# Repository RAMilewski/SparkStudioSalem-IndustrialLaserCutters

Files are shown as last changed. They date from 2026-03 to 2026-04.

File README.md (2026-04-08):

# Industrial 6090 150Watt CO2 Laser Cutters

This repository collects information about the Industrial
scale CO2 laser cutters at Spark Studios including
policies, safety information, training materials and technical
information such as wiring diagrams.

# Policies and procedures

This section covers the policies and procedures for operating the machines.

* Use of these machines is governed by the [Policies](policies.pdf).
* When running jobs, please follow the [Operations Checklist](operation-checklist.pdf)
* When running jobs, please fill out a sheet in the [Operation Log](operation-log.pdf)
* Different materials should be cut and engraved with various settings.  While you may
  need to experiment to get the best results, the [Feeds and Speeds](FeedsAndSpeeds.pdf) document
  gives good starting points for common materials.
* To achieve better surface finishes, please refer to the [Pro Tips](pro-tips.pdf)
* These [Signs](signs.pdf) should be placed on the machines in event of malfunction to alert
  other users and Spark Studio board members of malfunctions.

If you wish th revise the policies, please edit the corresponding
OpenOffice (.odt) files and review with the Spark Studio Board.
Once approved, a pull-request can be sent to request that the official
copies of the policies be updated.  Note when revising policies, the
revision number and date MUST be updated in order to keep track
of which policy revision is the most recent.

# Technical Information

This section contains technical information for maintenance and
diagnosis of problems.  These are indended only for those tasked
specifically with maintaining and repairing the machines.  These
should not be used during normal operation.

This [operation manual](Gweike-operation-manual.pdf) covers
the use and operation of a similar laser cutter from Gweike.
While the laser cutters are not exactly this model, they
do give useful guidance on the machines and their operation.

The 6090 laser cutters are built using a Ruida controller
which interprets the GCode to guide the machine through making
cuts.  The [Ruida controller's documentation](RDC6445G-Control-System-V1.2-Manual.pdf)
describes more about its design and usage.

In addition, the [laser power supply has accompanying documentation](LASERPOWERSUPPLY欧规_1729590679720.pdf)
about its inputs and controls.

This [wiring diagram](laser-block-diagram.pdf) is
available for helping to understand the design of the
machines and general troubleshooting.  This diagram was produced
by reverse-engineering the design and is not authoritative,
but is as accurate as possible a diagram describing the wiring
of the machine based on its current configuration which has
been slightly altered from its original design.  The diagram is
authored in KiCad and future changes should be proposed and updated
using this format, reviewed, and implemented with the consent of
a Certifier or the Spark Studio Board.

# Modified Parts

Some parts have been designed and 3d printed in an effort to
improve the safety of the equipment.  These include:

* Spacers/stand-offs to hold a panel to prevent laser light from coming
  through the vent holes.
  
* Plugs for circular holes in front of Blue laser cutter.

* Holder for reed switch protecting the laser from firing with
  the door open.

The CAD for these files are maintained in this [FreeCAD file](LaserCutterParts.FCStd).

# Alignment Procedures

The performance of the machines is highly dependent on how well
the machine is aligned.  Specifically, the optics must be aligned
closely with the gantry and the gantry needs to be square and parallel to
the bed.  Alignment of the machine is something of an art, but the
procedures are roughly outlined in the [Laser Alignment Guide](LaserAlignmentGuide.pdf).
These alignment procedures make use of some 3d-printed targets and
a [Laser Beam Alignment Worksheet](LaserBeamAlignmentWorksheet.svg) to assist in visualizing the beam path
and adjustments needed to bring the beam into the correct orientation.

There are beam target fixtures that can be inserted into the
apertures of [Mirror #2](stl/LaserCutterParts-P_AlignmentTarget_Mirror2.stl)
and [Mirror #3](stl/LaserCutterParts-P_AlignmentTarget_Mirror3.stl)
and affixed with blue painter's tape and marked using the [aperture](stl/LaserCutterParts-P_AlignmentTarget_ScribeAperture.stl) and [aperture](stl/LaserCutterParts-P_AlignmentTarget_Scribe.stl) marking jigs so that objective measurements can be made of beam position at each point in the beam path.

Source models for each of these parts can be found in
the [FreeCAD file](LaserCutterParts.FCStd) in case modifications to the models
are required.

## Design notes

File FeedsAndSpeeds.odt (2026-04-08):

Feeds and Speeds

Feed rate (cutting speed) and Power (percentage of maximum laser power) typically need to be tuned for each material. Even among the same material, there is often variation, so the numbers presented here are just starting points. Some adjustment of these settings are usually necessary to achieve the results you’re looking for. Because of this, it is advised to cut some test samples before cutting a large project to ensure that you’re getting good results. Note that in order to extend the life of the laser, it is advised to never exceed 50% power.

## Material: Plywood

| Cut | | Engrave/Score
Thickness | Power (%) | Speed (mm/s) | Power(%) | Speed(mm/s)
3mm (1/8 in) | 50 | 30 | 15 | 200
5mm (3/16 in) | 50 | 10-13 | 15 | 200

## Material: Acrylic

| Cut | | Engrave/Score
Thickness | Power (%) | Speed (mm/s) | Power(%) | Speed(mm/s)
3mm (1/8 in) | 50 | 30 | 15 | 200
5mm (3/16 in) | 50 | 7-10 | 15 | 200

## Material: High density fiber board (Hardboard or HDF)

| Cut | | Engrave/Score
Thickness | Power (%) | Speed (mm/s) | Power(%) | Speed(mm/s)
3mm (1/8 in) | 50 | 30 | 15 | 200
5mm (3/16 in) | 50 | 10-13 | 15 | 200

## Material: Ceramic Tile

| Cut | | Engrave/Score
Thickness | Power (%) | Speed (mm/s) | Power(%) | Speed(mm/s)
Any | N/A | N/A | 15 | 200-300

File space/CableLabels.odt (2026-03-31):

Network Cables

5G Router

Internet Ingress

See Network Diagram

5G Router to SW1

SW1

Ethernet Switch

See Network Diagram

SW1 to 5G Router

SW1 to SW2

Access Point 1

See Network Diagram

Access Point 1 to SW1 (PoE Port)

Access Point 2

See Network Diagram

Access Point 2 to SW2 (PoE Port)

SW2

Ethernet Switch

See Network Diagram

SW2 to SW3

SW2 to Access Point (PoE Port)

SW3

Ethernet Switch

See Network Diagram

SW3 to SW2

SW3 to Gweike Laser

SW3 to Blue Laser

Breaker Labels

Breaker: B1 : Northwest Warehouse Plugs

Breaker: B3 : Bathroom

Breaker: B3 : Bathroom

Breaker: B3 : Bathroom

Breaker: B5 : Warehouse Heater

Breaker: B7 : Loft lights and network

Breaker: B9 : Unterminated (danger)

Breaker: B11,B13 : 220VAC Under breaker panel

Breaker: B15,B17 : Mini-split AC unit

Breaker: B19 : Conference room

Breaker: B19 : Conference room

Breaker: B19 : Conference room

Breaker: B19 : Conference room

Breaker: B21 : East Wall “Pop” (Blue&White Laser cutter)

Breaker: B23 : East Wall “Crackle” (Gweike)

Breaker: B25 : Northeast Wall 3d printers, “Snap” GlowForge

Breaker: B27 : East Wall Electronics Bench

Breaker: B2 : Warehouse Lights

Breaker: B4, B6 : Water Heater

Breaker: B8 : Overhead Power Drop

Breaker: B10 : Outside Lights

Breaker: B12,B14 : Do not turn off/ Unknown(?)

Breaker: B16,B18 : Bathroom Heater

Breaker: B20,B22,B24 : Laser Exhaust Fans

Breaker: B26,B28,B30 : Air Compressor Panel

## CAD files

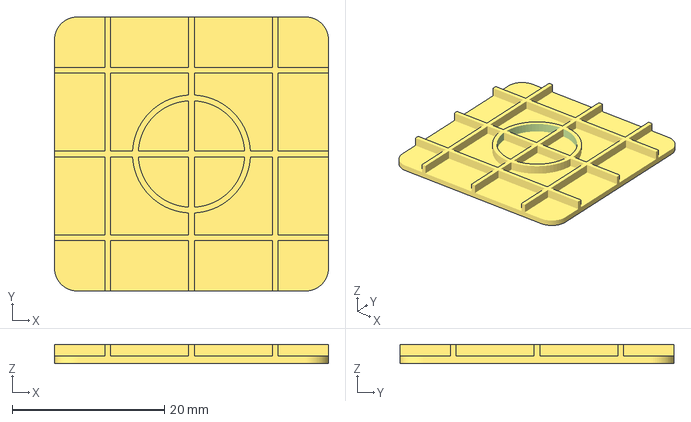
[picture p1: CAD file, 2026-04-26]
3mf/StampSurface.3mf
36.0 x 36.0 x 2.50 mm

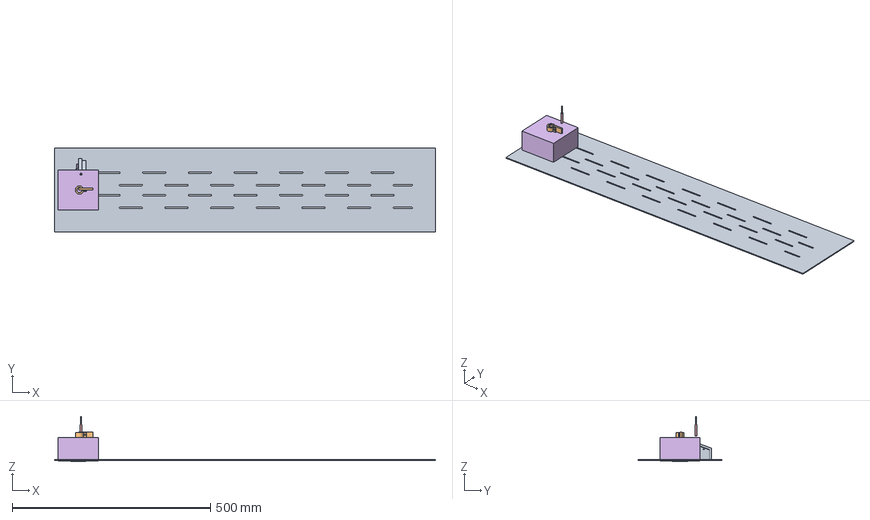
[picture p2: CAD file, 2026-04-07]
LaserCutterParts.FCStd
961.4 x 211.8 x 114.3 mm
B_FrontPanel
B_FrontPanelBaffle_Spacer
B_FrontPanelBaffle_Endcap
B_LimitSwitchSpacer
B_HolePlug_FrontPanels
B_HolePlug_Tester
B_ReedSwitch_Magnet
B_ReedSwitch_Holder
B_Cabinet_Body
B_Cabinet_Lid
B_ReedSwitch
B_CAMTest
B_TPLinkBracket_Right
B_TPLinkBracket_Left
B_AlignmentWrench1
B_AlignmentWrench2
B_AlignmentTarget_Mirror3
B_AlignmentTarget_Mirror2
B_HolePlug_SidePanels
B_AlignmentTarget_Stamp
B_AlignmentTarget_Scribe
B_IndicatorMount
B_AlignmentTarget_ScribeAperture
B_AlignmentTarget_HeadTube
B_AlignmentTarget_HeadTarget
B_LaserPointerMount
B_LaserPointerMountAperture
Model-P_CAMTest
CutTool
Stock
5mm Endmill

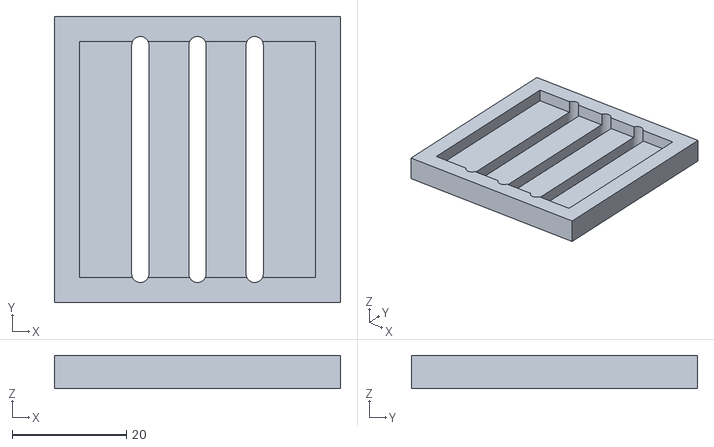
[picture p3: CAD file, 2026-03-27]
stl/LaserCutterParts-P_AlignmentTarget_Scribe.stl
50.0 x 50.0 x 5.80

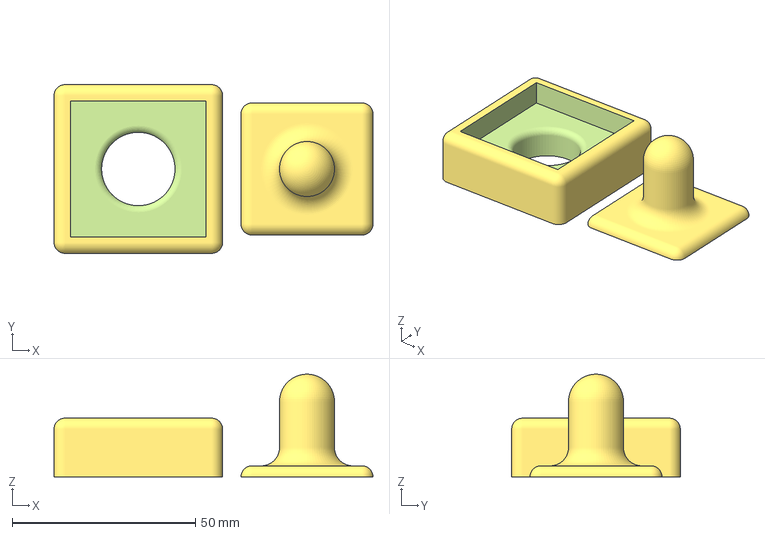
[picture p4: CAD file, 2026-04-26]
3mf/AlignmentStamp.3mf
87.0 x 46.0 x 28.0 mm

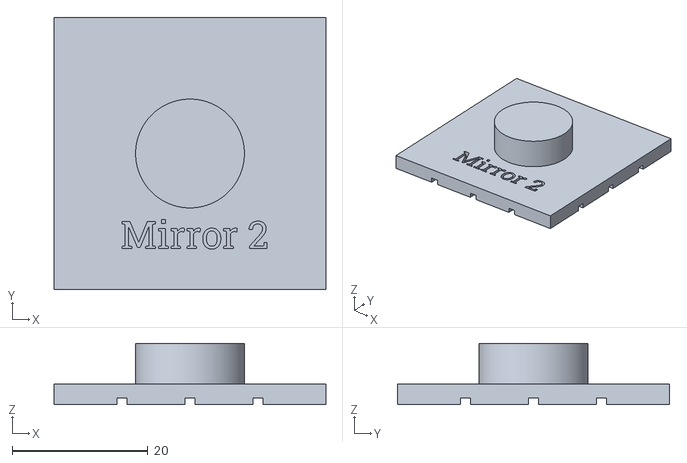
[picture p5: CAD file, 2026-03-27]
stl/LaserCutterParts-P_AlignmentTarget_Mirror2.stl
40.0 x 40.0 x 9.00

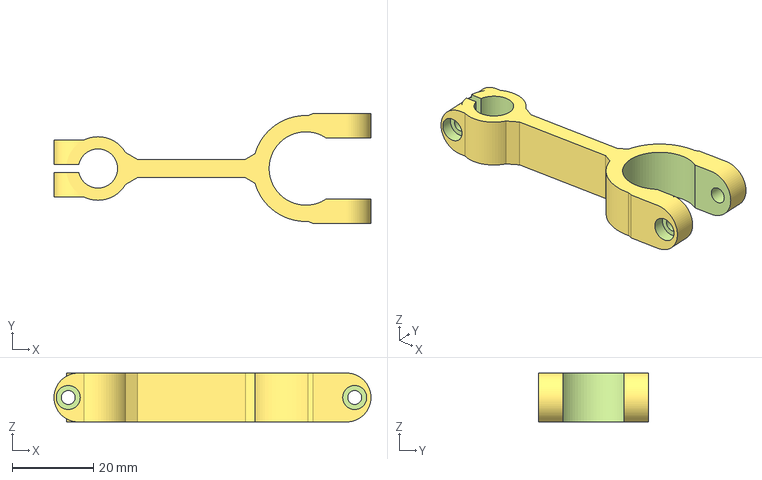
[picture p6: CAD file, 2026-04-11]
3mf/dial_holder.3mf
77.8 x 27.0 x 12.0 mm

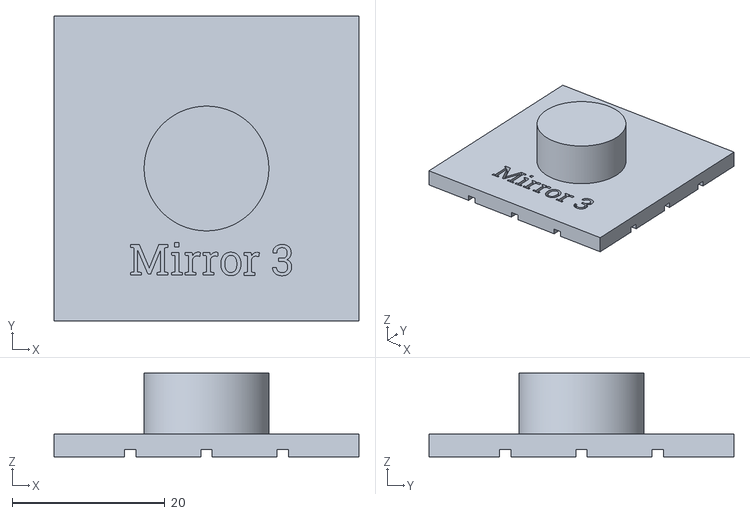
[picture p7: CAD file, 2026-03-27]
stl/LaserCutterParts-P_AlignmentTarget_Mirror3.stl
40.0 x 40.0 x 11.0

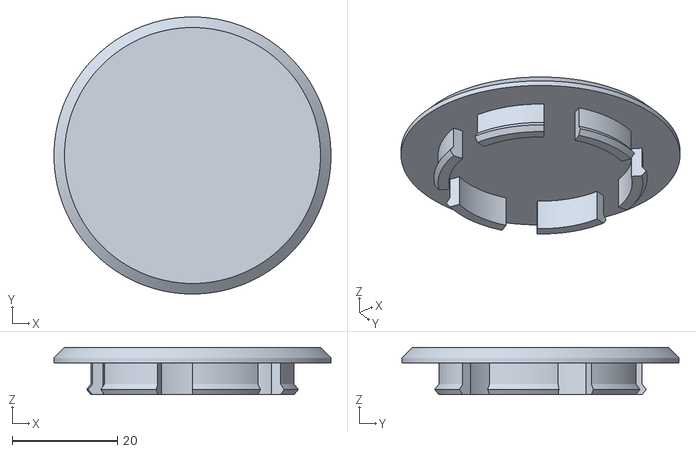
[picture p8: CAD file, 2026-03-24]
stl/LaserCutterParts-P_HolePlug_FrontPanels.stl
52.6 x 52.6 x 9.00

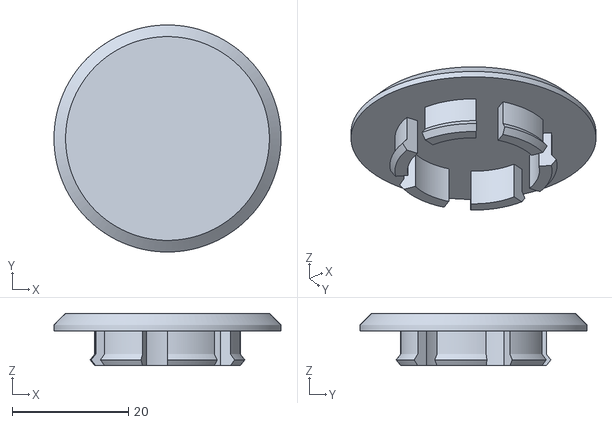
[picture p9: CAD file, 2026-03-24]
stl/LaserCutterParts-P_HolePlug_SidePanels.stl
39.0 x 39.0 x 9.00

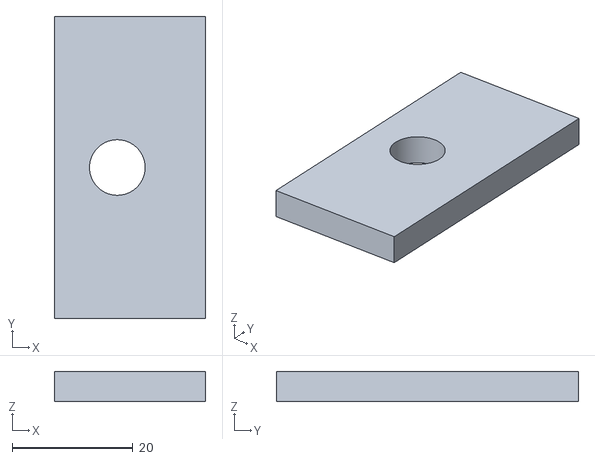
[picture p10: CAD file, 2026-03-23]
stl/LaserCutterParts-P_LimitSwitch_Magnet.stl
25.0 x 50.0 x 5.00

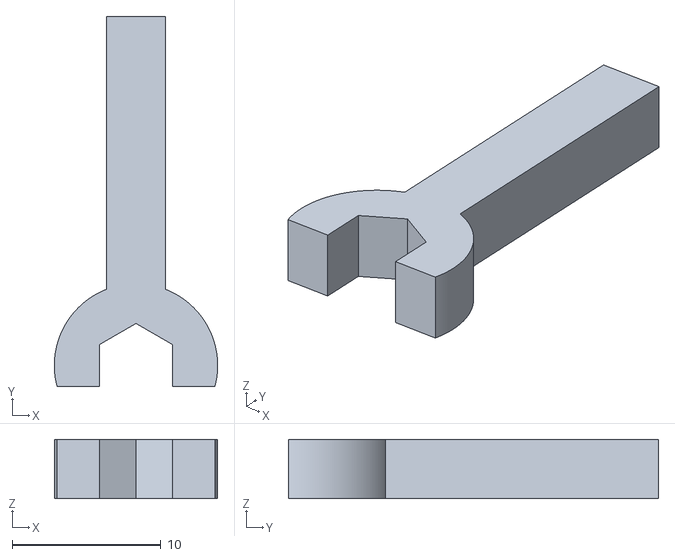
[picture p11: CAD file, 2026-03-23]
stl/LaserCutterParts-P_AlignmentWrench1_4_9mm.stl
11.0 x 24.9 x 4.00

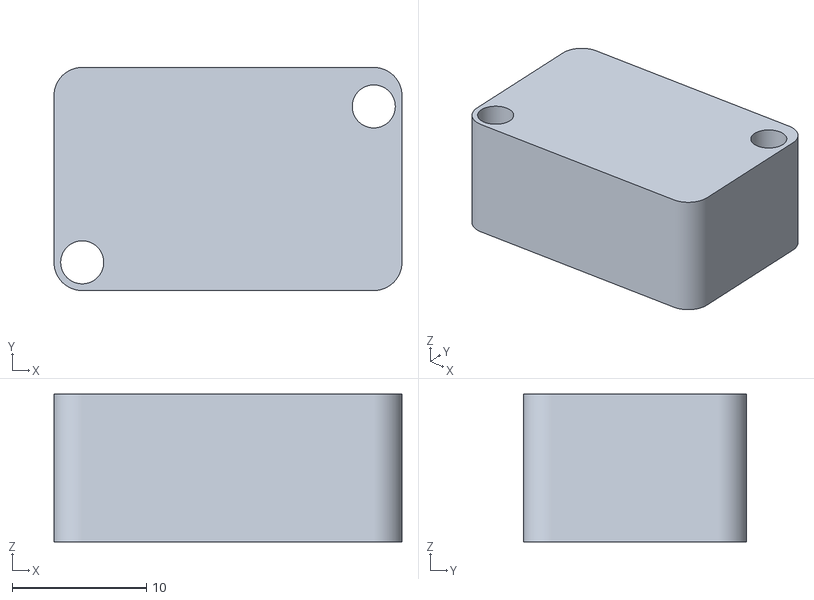
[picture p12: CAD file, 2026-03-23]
stl/LaserCutterParts-P_LimitSwitchSpacer.stl
25.9 x 16.6 x 11.0

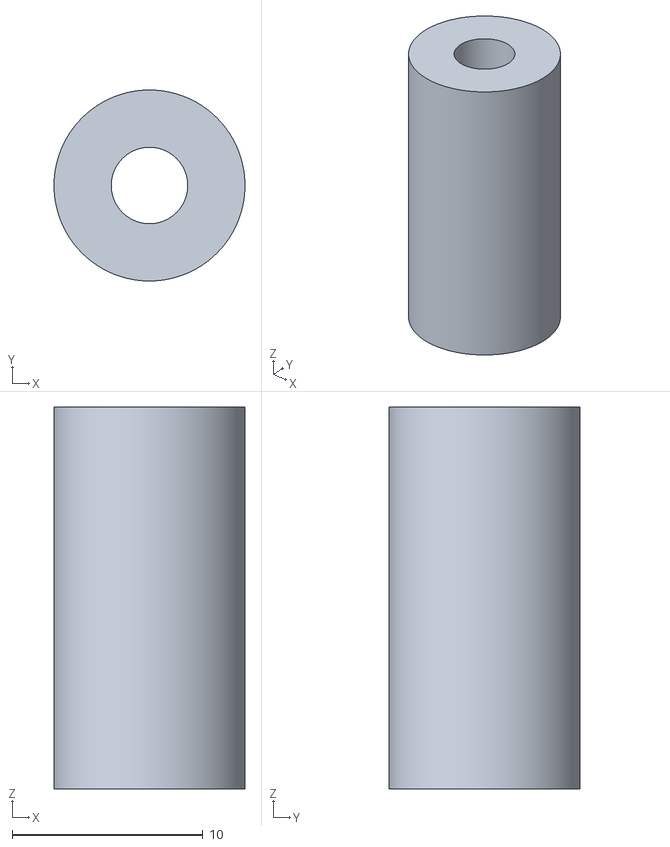
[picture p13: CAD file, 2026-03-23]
stl/LaserCutterParts-P_Spacer.stl
10.00 x 10.00 x 20.0

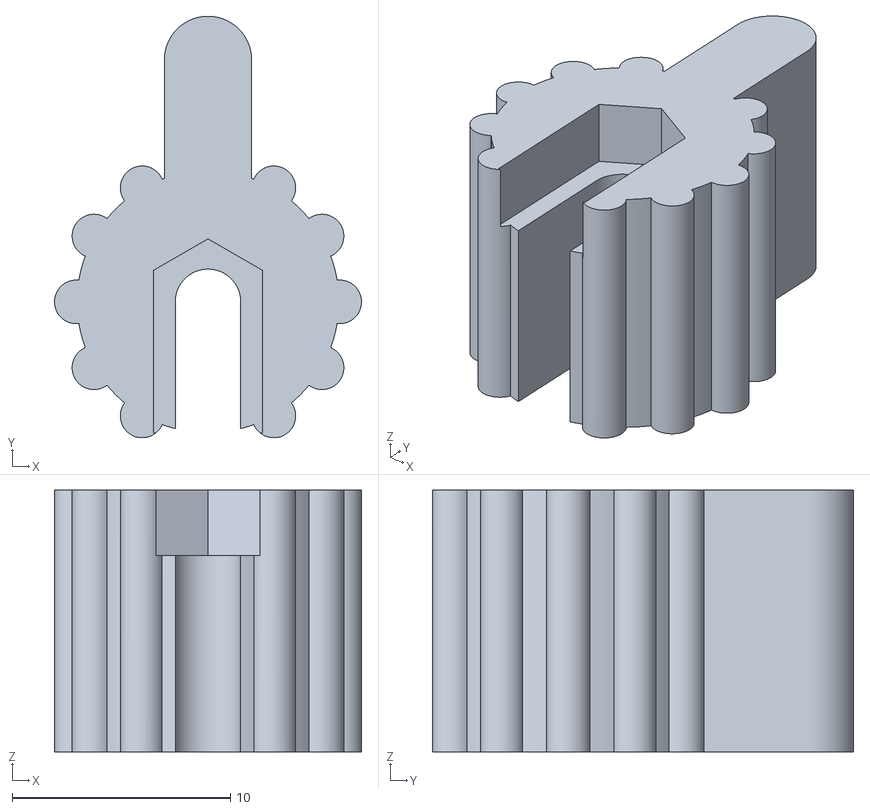
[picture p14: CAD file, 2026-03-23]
stl/LaserCutterParts-P_AlignmentWrench2.stl
14.1 x 19.3 x 12.0

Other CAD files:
stl/LaserCutterParts-P_AlignmentTarget_ScribeAperture.stl
stl/LaserCutterParts-P_ReedSwitch_Magnet.stl
stl/LaserCutterParts-P_AlignmentWrench2_5mm.stl
stl/LaserCutterParts-P_AlignmentWrench1_5mm.stl
OpenSCAD/AlignmentStamp.scad
OpenSCAD/dial_holder.scad
stl/LaserCutterParts-P_AlignmentWrench.stl
stl/LaserCutterParts-P_AlignmentWrench1_5_1mm.stl
stl/LaserCutterParts-P_AlignmentWrench2_4_9mm.stl
stl/LaserCutterParts-P_AlignmentWrench2_5_1mm.stl
stl/LaserCutterParts-P_Endcap.stl
stl/LaserCutterParts-P_HolePlug_FrontPanelsTester.stl
stl/LaserCutterParts-P_LimitSwitch_Switch.stl
stl/LaserCutterParts-P_PowerBox_Body.stl
stl/LaserCutterParts-P_PowerBox_Lid.stl
stl/LaserCutterParts-P_ReedSwitch_Holder.stl
stl/LaserCutterParts-P_TPLinkBracket.stl
stl/LaserCutterParts-P_TPLinkBracket_Left.stl
stl/LaserCutterParts-P_TPLinkBracket_Right.stl

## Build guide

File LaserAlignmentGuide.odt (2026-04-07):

Outline of procedures to align the gantry, optics, and bed

# Introduction

The performance of these laser cutters is highly dependent on how well the machine is aligned and calibrated. The alignment of the machine is something of an art and requires patience and understanding of the fundamentals of optics. Fortunately, if inspected regularly, the full procedure is rarely needed. This document contains an outline of the main alignment procedures and also a monthly maintenance guide. Once aligned, the machine should be maintained by following the monthly inspection process to verify that the machine is still adequately aligned and perform minor adjustments as needed. This is intended to ensure that the full alignment process is needed only rarely and that most of the time, only minor adjustments are needed to keep the machine in working order.

# Alignment Procedure Outline

## 1. Gantry Skew

In this stage, we aim to align the gantry so that the left and right rails are parallel. Using a bubble-level, check that each of the rails is angled from front-to-back by the same amount. If necessary, the entire machine can be trammed so that they are both level as closely as possible. Note that precise alignment is not necessary, but try to get the left and right rails within about 1 degree of the same angle front-to-back. The height of the front anchor point of each of the rails can be adjusted by loosening the screws holding the Y axis rails to the chassis and moving them higher or lower. Continue iterating on this until they are as close to parallel as you can make them. [Ref 1].

This is not too crucial for the optics because mirror #2 rides along the rails. Any “skew” in the yz plane will be washed out because the mirror moves with the rail. Nonetheless, make an effort to ensure that the rails are as level as possible in reference to one another.

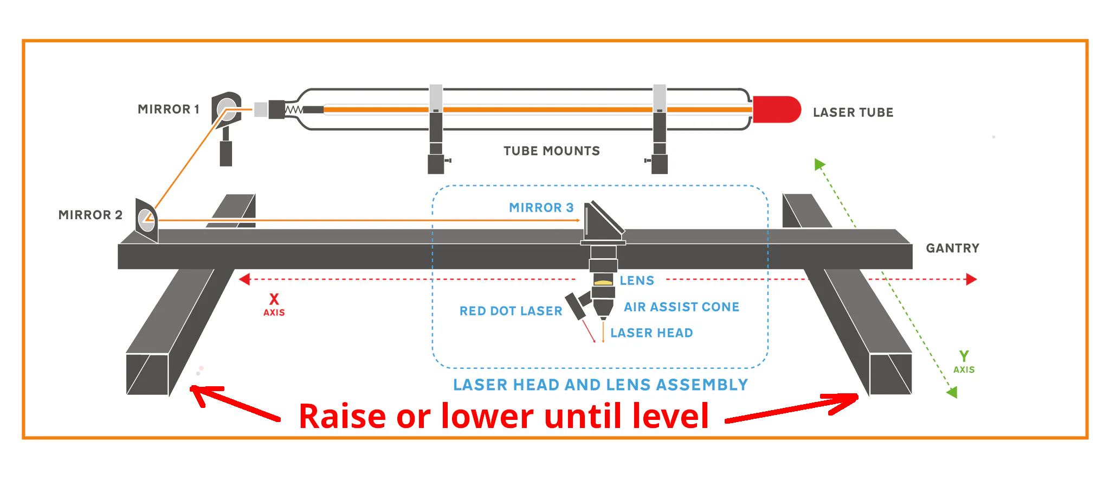
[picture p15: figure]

Measuring gantry skew. In order to check the gantry for skew, use a piece of fine thread stretched taught on the two diagonals of the gantry rails. If the gantry is square in the YZ plane, the two threads will intersect at the center. If one is higher or lower, then the rails are not perfectly parallel. Raise or lower the gantry until the two threads are just barely touching. You can secure the thread at each end with magnets or tape so they remain tight while making adjustments. Make sure to remove the thread after adjustment.

## 2. Gantry Mirror Interference

It sometimes happens that mirror #2 mounted on the gantry is accidentally bumped by the drag chain, cables, or other impediments. It only takes a microscopic deflection to move the mirror and thus beam spot at the far end of the machine. Take care to ensure that the cables, drag chain, and other moving parts do not bump or interfere with the free motion of the mirror mounted on the gantry.

## 3. Bed Leveling

In this stage, we aim to ensure that the XY plane of the bed is parallel to the XY plane of the gantry. The easiest way to do this is to place a large rigid, square object on the bed. Ideally, this object should be a) flat b) rigid, and c) cover the entire bed.

Next, jog the laser head to each of the 4 corners and use a small flat object to move the laser head so that the lowest of the 4 corners just touches the object. Our aim from here will be to adjust the z-axis lead screws so that all 4 corners match. To adjust one of the lead screws, use a hex wrench to loosen the set screw for the sprocket for that lead screw and manually adjust the lead screw until it just touches the object or the dial indicator reads the correct height. Re-tighten the set screw for the sprocket to lock the position in place. Continue this process until all 4 corners read the same height in reference to the tip of the laser tube.

For extra precision, a dial indicator can be mounted on the laser lens tube. Once done, the laser head can carefully be moved around the bed to measure how much deviation there is across the bed. A good alignment should yield something on the order of 10 thousandths of an inch (0.254mm)

This image depicts using a dial-indicator mounted on the laser lens aperture to measure relative height of the bed against the plane of the gantry. Note that the indicator SHOULD NOT BE MOUNTED UNTIL THE CONTROLLER HAS BEEN TURNED ON AND HOMED. You don’t want the indicator to be dragged by the controller over the bed during homing as this can damage the indicator and possibly crash the head.

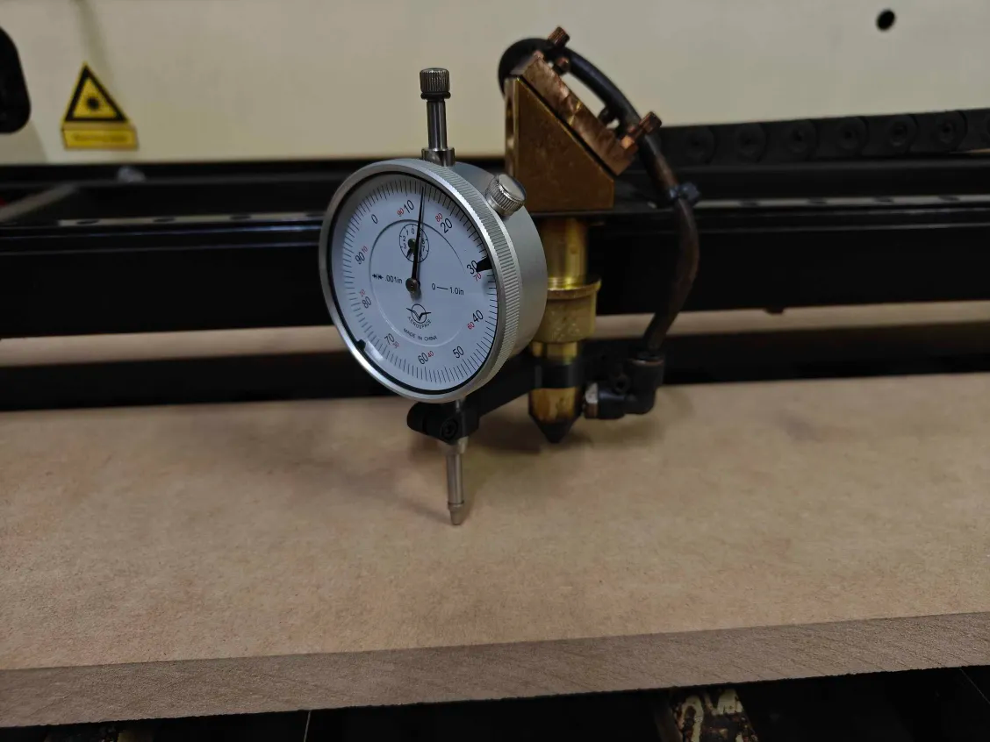
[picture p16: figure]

Once the indicator can measure the height in different locations, the bed can be adjusted carefully to raise or lower the corners until the bed and gantry are in the same plane.

[Ref 2]

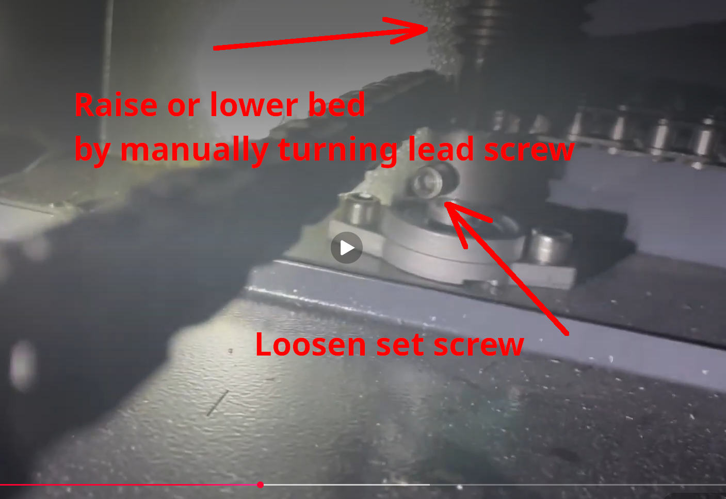
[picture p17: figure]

## 4. Tube Adjustment

In this stage, we aim to ensure that the laser beam arrives at mirror #1 in the center of the aperture. In order to do this, it may be necessary to shim the laser tube or make fine adjustments to the tube location until the beam arrives at the center as parallel as possible. Note that it is difficult to ensure that the tube is exactly perpendicular to the aperture because there is only a very small gap between the end of the laser tube and the aperture, but align it as closely as possible with the naked eye. Alignments of the mirrors will make up for small deviations from the correct angle.

## 5. Mirror 1 Adjustment

In this stage, we aim to ensure that the laser beam arrives at mirror #2 at the center of the aperture.

Place a piece of blue painter’s tape over one of the “Mirror 2 Target”, mark the grid and aperture location with a pen using the accompanying templates. These markings will assist in objectively knowing the position of the test pulse in reference to the aperture and a 10x10mm grid.

Then, place the target in the input aperture of mirror #2. Close the lid and power on the laser. Fire a test pulse at 10% power with the laser head in the upper-left corner of the bed (closest to the laser head). Repeat this process in the lower-left corner. If the pulses arrive in different locations, carefully adjust the set-screws on mirorr #1 for the up/down and left/right to move the beam in the desired direction. Note that when adjusting the mirror, the one in the “lower” corner will move a larger distance than the one in the “upper” corner. Repeat this adjustment until both pulses arrive in the approximate center of the aperture and as close to one another as possible.

Note that after aligning mirror #2, it may be necessary to further adjust mirror #1, but this should be the approximate starting location for further alignment.

## 6. Mirror 2 Alignment

In this stage, we aim to ensure that the laser beam arrives at mirror #3 (the mirror on the laser head) in the exact center of the aperture consistently all the way across the bed.

Place a piece of blue painter’s tape across one a “Mirror 3 Target” and mark the grid and aperture location with a pen using the accompanying templates. These markings will assist in objectively knowing the position of the test pulse in reference to the aperture and a 10x10mm grid.

Then place the target in the input aperture of mirror #3. Jog the laser head to the upper-left corner of the bed. Fire a test pulse at 10% power. Repeat this for each of the 4 corners. It is sometimes helpful to save these pulses by sticking them to a copy of the “Laser Alignment Worksheet”. This will give the location of the pulses on each of the 4 corners of the bed.

Adjusting the set-screws on mirror #2 will move each of those pulses up and down or left and right. Note that there will be more movement of the beam on the right side than the left, but the motion of them should be approximately the same. For example, if the upper-right and lower-right test spots are both 4mm high, you would want to adjust mirror #2 downward. Doing this would move both the upper-right and lower-right spots downward by the same amount. It is usually not the case that they will move in different directions or by different amounts.

Also note that the right side spots will move more than the left-side spots. This is because the left-side spots are a very small distance from mirror #2 than the right-side spots.

Begin the adjustment by carefully adjusting the “left/right” screw until all 4 spots are as close to the center as possible and cluster around it. For example, if they’re not quite aligned, you goal would be to put one spot slightly to the left and the other slightly to the right. Once the left/right is approximately on center, proceed to the “up/down” adjustment.

Again, for the “up/down” adjustment of mirror #2, you should aim to get all 4 spots as close to the center as possible. If they’re not quite aligned, you should aim to get them evenly distributed above/below so that “on average” they’re in the same location.

If the 4 test spots are within about 1-2mm of center, that is usually sufficient. If so, skip to step 8. If not, it may be required to re-adjust mirror #1 (Step 6) and then come back to mirror #2 (Step 5).

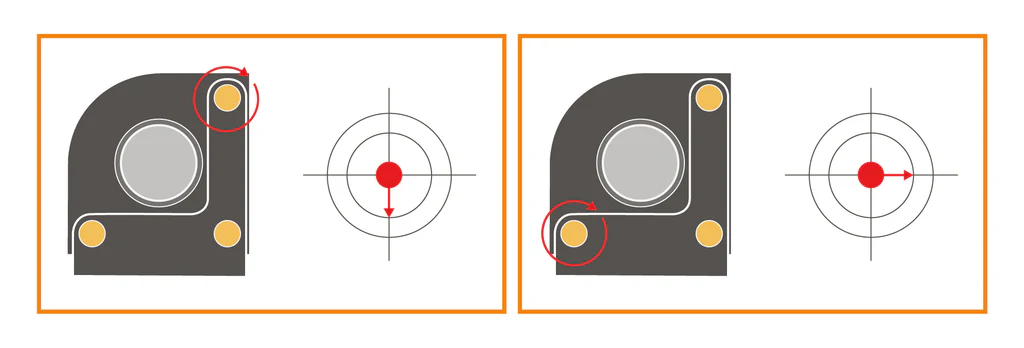
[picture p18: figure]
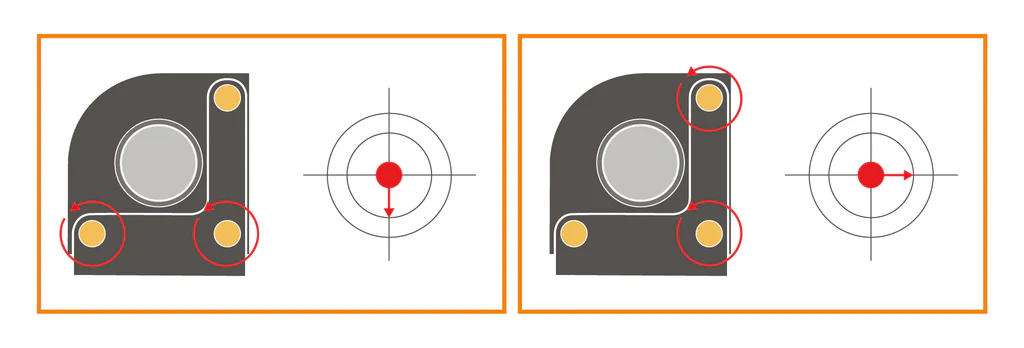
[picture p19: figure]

[Ref 1]

## 7. Mirror #1 fine-tuning

Because adjustment of mirror #2 will move the spots on the right side (furthest from the mirror) by approximately the same amount, mirror #2 usually cannot compensate for the fact that the right-side spots are not consistent from front to back of the machine. This is because the beam length traveled and mirror angle are the same for these locations. In order to adjust the location of the spots relative to one another, it will be necessary to very slightly adjust mirror #1. This is because the length of the path from the upper-right to mirror #1 is shorter than the length of the path from the lower-right to mirror #1.

The goal of this alignment is to VERY SLIGHTLY alter the direction of the beam until the spots in the upper-right and lower-right hit at the same location EVEN IF THEY ARE NOT IN THE CENTER. Centering these spots will be done by returning to step 5. where both can be moved at the same time using mirror #2. This alignment only aims to make sure that the amount they of off by is the same.

Return to step 5 to re-center the spots. Note that after this fine-tuning adjustment, the spots from the original mirror #1 alignment may no longer arrive at the exact center of the aperture. This is ok as long as the spots arrive at the center of mirror #3 consistently across the bed.

## 8. Mirror #3 alignment

The goal of this stage is to ensure that the beam arrives at the center of the lens. There is no alignment target for this, so adjustment will have to be done without a specific target.

Remove the lens from the laser head and place a piece of blue painter’s tape on the bottom. Score or mark the painter’s tape so that the aperture can be judged. Fire a test pulse to mark the painter’s tape. Carefully adjust the set-screws on mirror #3 and repeat this process until the spot arrives as close as possible to the center of the output aperture (where the lens will be).

Once this is done, place a piece of tape on the bed and fire a test-pulse. Move the bed to its lowest position and fire another test-pulse. Continue adjusting mirror #3 until the two pulses (highest Z to lowest Z) arrive are at the same location. This process ensures that the beam is aligned so that it is perfectly perpendicular to the work surface.

## 9. Gantry Square

The goal of this step is to make sure that the gantry is truly square. This must be done after step 7 because it relies on having a consistent beam all across the bed in order to mark a square.

Perform a test etch on a piece of material as large as possible. The test etch should be done at low power (~15%) and high speed (~200mm/s). The test pattern should be a large rectangle with lines across the two diagonals [Ref 3].

With these two diagonals marked on the large workpiece, measure the length of the diagonals carefully. If you find one of them significantly longer than the other, you should square the gantry. If they are the same length then the gantry is already square.

In order to adjust the gantry square, disengage the set-screws that tie the left side and right side of the gantry cross-member so that they move independently. The gantry cross-member can then be carefully moved clockwise or counter-clockwise by a few degrees. VERY SLIGHTLY adjust the angle of the gantry cross-member and repeat the rectangle and diagonals test. Repeat until the lengths of the two diagonals match.

Note that in the process of adjusting the diagonals, it may be necessary to return to the mirror adjustment stage, so repeat the test marks from steps 5-7 to confirm that the beam is still centered in the aperture and perpendicular to the work surface at the end.

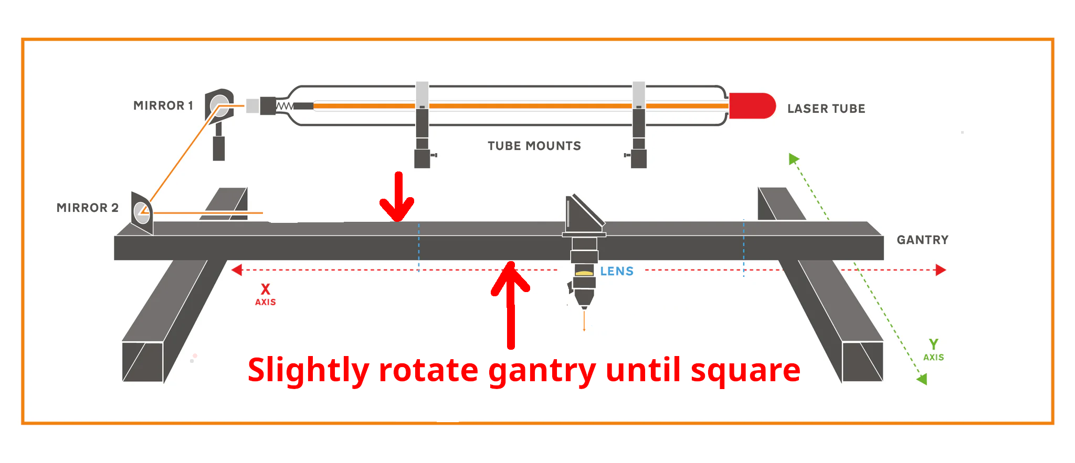
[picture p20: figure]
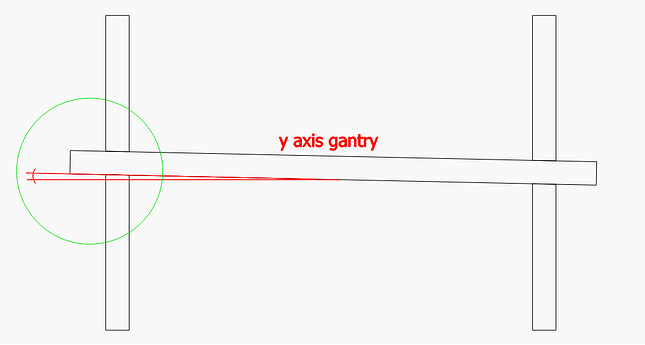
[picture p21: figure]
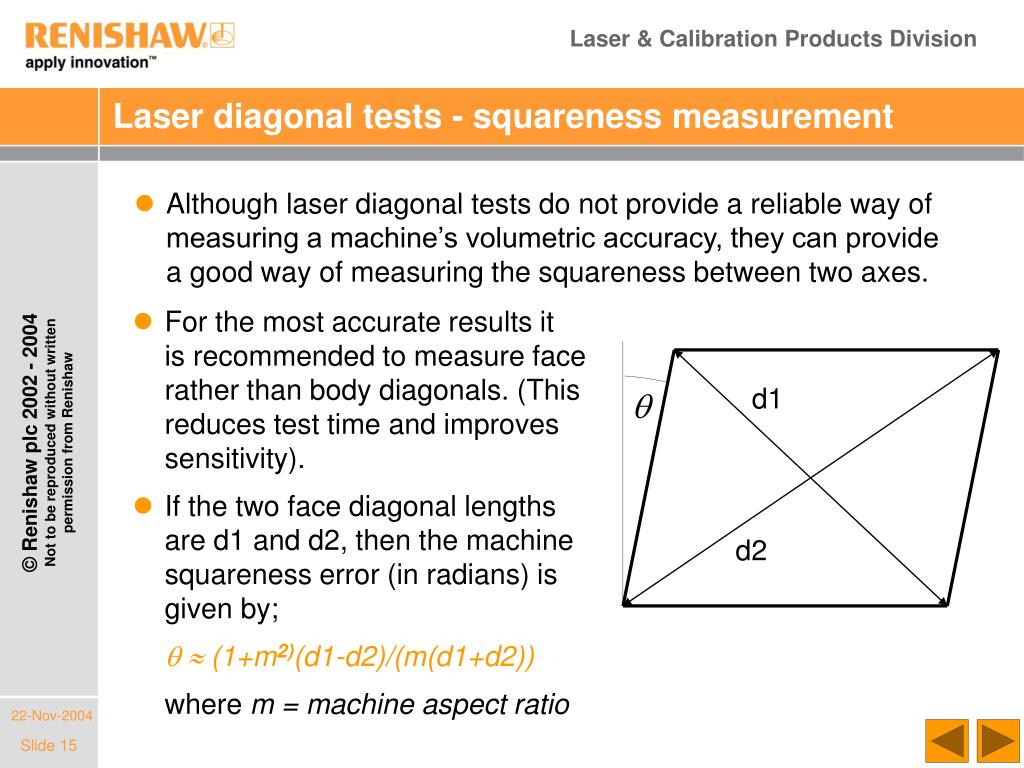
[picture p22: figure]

Rather than marking an entire rectangle, it suffices to mark 4 spots at each corner of the bed. This can be done inexpensively by fixing a small piece of cardboard or other sacrificial media at each corner of the bed. The laser can then be test-fired and the diagonal corners can be measured. This avoids the cost of using a very large sacrificial test piece to mark. The only thing that is important is that the points are marked and don’t move between the time they are marked and the time they are measured.

# Monthly Inspection

The machine should undergo a monthly inspection wherein the working state should be verified. This process consists of verifying the cleanliness of the optics followed by a set of alignment tests to verify and correct any deviations from the last alignment.

## 1. Inspect and clean optical elements

The first thing to do is to check all 3 mirrors for residue from recent cutting activity. During this inspection, if necessary, clean each of the mirrors with q-tips and “LA’s totally awesome” detergent followed by 97% isopropyl alcohol to ensure that they are clean and free of residue and debris.

Next, the lens should be inspected and cleaned with the same method. Note any pitting or scarring of the lens itself as this could be indicative of damage to the lens from the residue.

As this is being done, if there is more residue than normal, check the operator log sheets to see what has been cut. This may inform future policy on materials, power and speed recommendations.

## 2. Bed level tests

Check to make sure that the bed is still parallel to the gantry. This is done by placing a small block between the nozzle and the bed at each of the 4 corners. The distance should be the same for all 4 corners. If one or more corners are not aligned to within about 1mm, perform the bed level procedure (See Step 2 in the alignment procedures).

For better accuracy, a dial indicator can be mounted to the laser head and the indicator can be run along the bed (with a suitably flat workpiece on the bed). The dial indicator will help align the bed to a much higher precision. In some cases, precision of about 0.25mm (10 thou inches) can be achieved in this way with a little patience.

## 3. Laser beam alignment tests

Next, the beam itself can be checked. Using the Laser Beam Alignment worksheet, fire test pulses using the targets with the laser head at each of the locations shown. This alignment worksheet will help visualize how close the beam is to the center of the apertures. Specifically, the Mirror #3 aperture should have test spots as close as possible to the center and within the aperture hole. If any of the spots are more than 2mm from the center, perform the alignment procedures in steps 4-7 depending on how the spots are mis-aligned. Make sure that the set-screws on the mirrors are tight after alignment so that the alignment does not drift during operation.

## 4. Gantry Square Test

Once the level, optics, and beam have been verified, the machine should be checked as square. This can be done by firing a test pulse at each of the 4 extreme corners of the bed with small pieces of cardboard or other sacrificial medium. The distance between diagonals should be checked to make sure they are equal. If they are not, square the gantry as described in Step 8. Note that this process may upset the alignment of the beam, so if it is found to be out of square, the mirrors may need subsequent alignment.

After all of the alignment tests have been done, file the Laser Beam Alignment worksheet in the folder for the specific machine and note the date and time, your name, and any notes on how you found the condition of the machine to be.

References:

[1] https://smokeandmirrors.store/pages/laser-beam-alignment-guide

[2] https://youtu.be/gCL-B2hnpUc

[3] https://www.youtube.com/watch?v=dyShfEqjyU4

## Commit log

2026-03-23 Added STLs so we can print them and added a beam alignment worksheet and beam target
    [LaserCutterParts-P_AlignmentTarget.stl, LaserCutterParts-P_AlignmentWrench.stl, LaserCutterParts-P_AlignmentWrench1_4_9mm.stl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]
2026-03-24 Removed un-needed/obsolete STLs.
    [LaserCutterParts-P_AlignmentTarget_Mirror2.stl, LaserCutterParts-P_AlignmentTarget_Mirror3.stl, LaserCutterParts-P_HolePlug_38_6mm.stl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]
2026-03-24 Updated latest CAD models for hole plugs
    [LaserCutterParts-P_HolePlug_FrontPanels.stl, LaserCutterParts-P_HolePlug_SidePanels.stl]
2026-03-25 Added nameplates and laser alignment targets.
    [LaserCutterParts-P_AlignmentTarget.stl, LaserCutterParts-P_AlignmentTarget_Mirror2.stl, LaserCutterParts-P_AlignmentTarget_Mirror3.stl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]
2026-03-25 Added network map, electrical map
    [network-topology.kicad_pcb, network-topology.kicad_sch]
2026-03-26 Added test pattern for captain laser
2026-03-27 Updated README and made a first draft of the alignment procedures guide.
    [LaserCutterParts-P_AlignmentTarget_Mirror2.stl, LaserCutterParts-P_AlignmentTarget_Mirror3.stl, LaserCutterParts-P_AlignmentTarget_Scribe.stl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]
2026-03-28 Updated captain laser, made corrections in electrical panel and filled out alignment guide a bit better.
2026-03-31 Updated electrical panel labels and added a new callibration object.
    [LaserCutterParts.FCStd]
2026-04-07 Fixed alignment worksheet and alignment guides. Also added QR codes to signs.
    [LaserCutterParts.FCStd]
2026-04-11 Add dial holder
    [dial_holder.3mf, dial_holder.scad]
2026-04-26 Alignment Stamp
    [AlignmentStamp.3mf, AlignmentStamp.scad, StampSurface.3mf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]
